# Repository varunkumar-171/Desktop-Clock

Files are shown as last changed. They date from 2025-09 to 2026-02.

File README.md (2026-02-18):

# Desktop-Clock

| PCB - Back View | PCB - Front View |
| :---: | :---: |
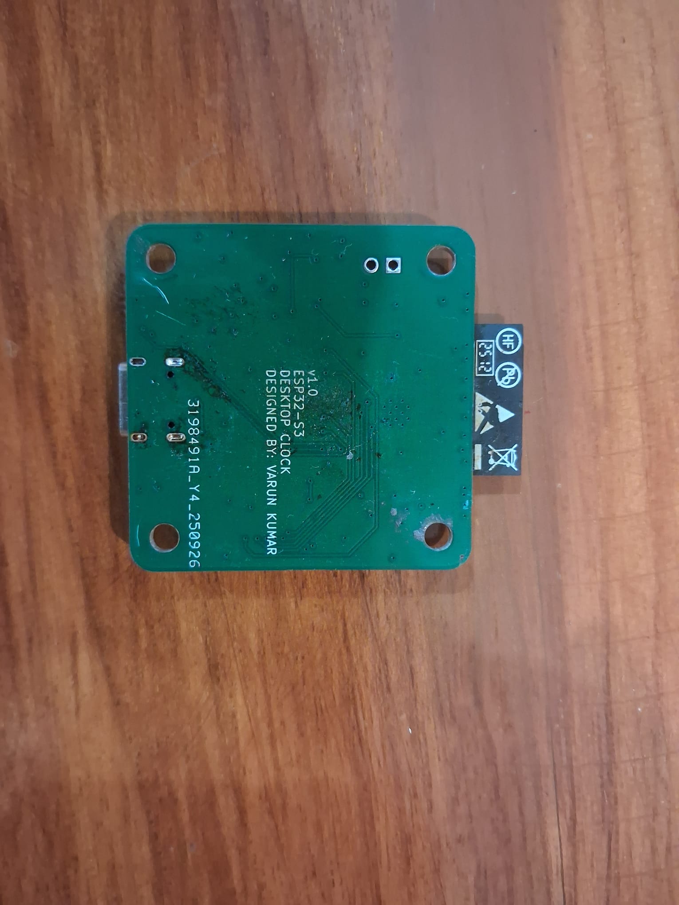
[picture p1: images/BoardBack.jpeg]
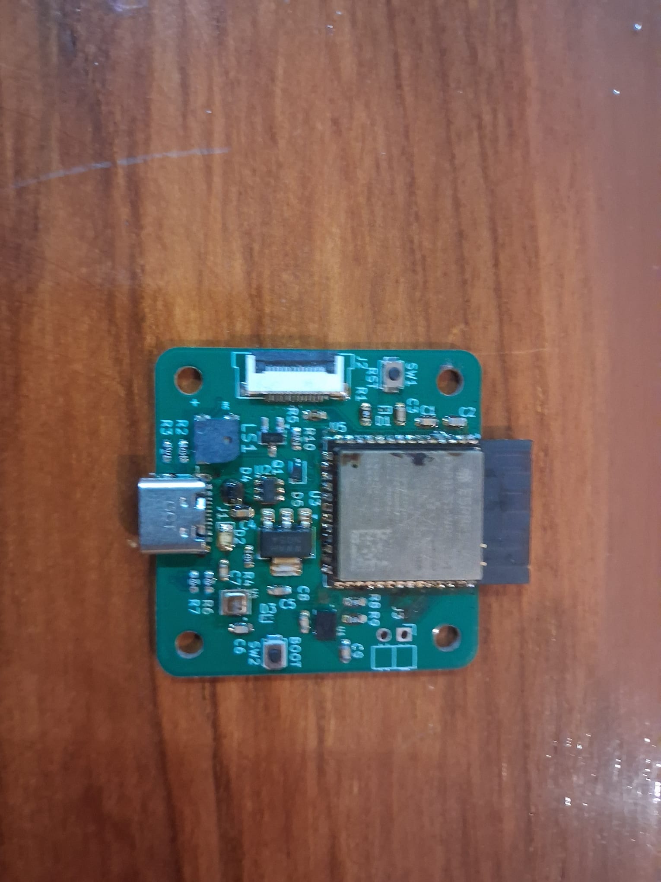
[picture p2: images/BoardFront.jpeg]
|  |  |

| Clock - Front View | Clock - Side View |
| :---: | :---: |
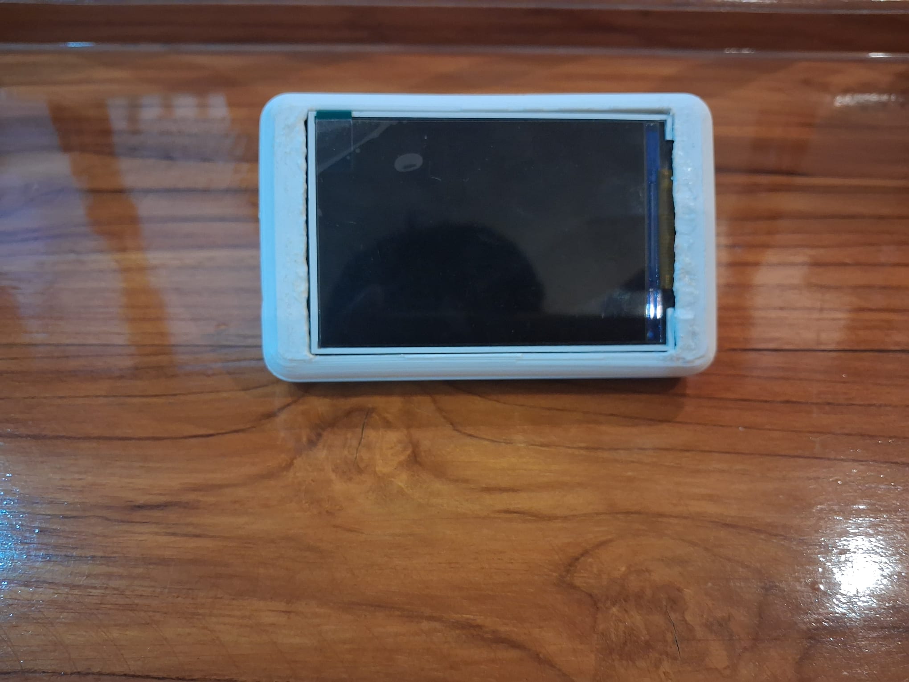
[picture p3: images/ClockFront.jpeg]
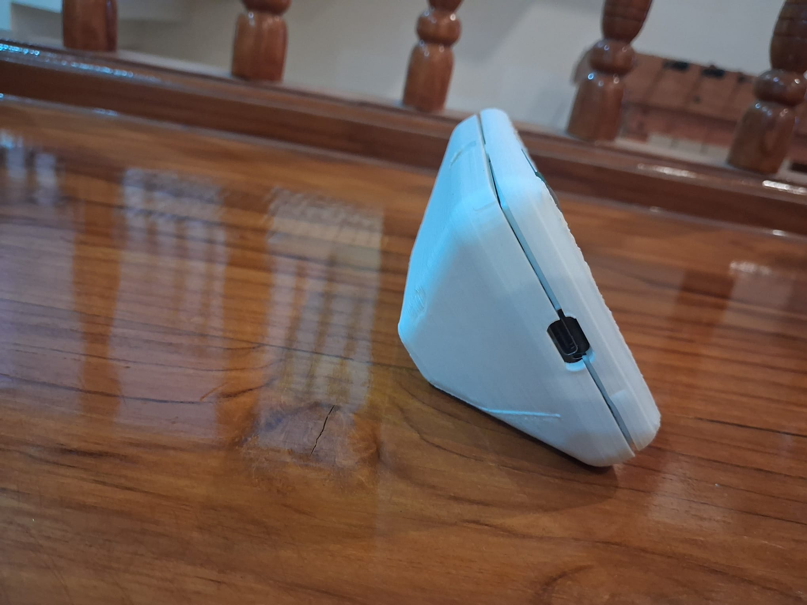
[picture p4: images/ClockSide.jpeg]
|  |  |

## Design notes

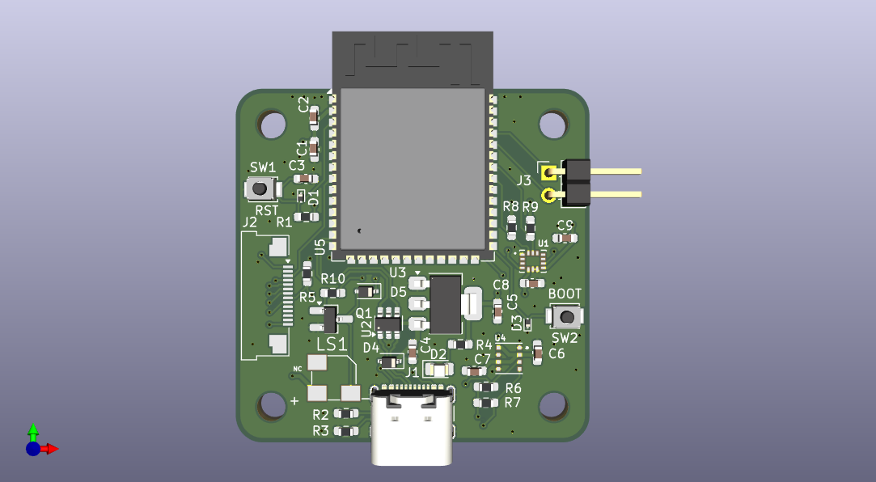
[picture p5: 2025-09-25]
hardware/DesktopClock.png

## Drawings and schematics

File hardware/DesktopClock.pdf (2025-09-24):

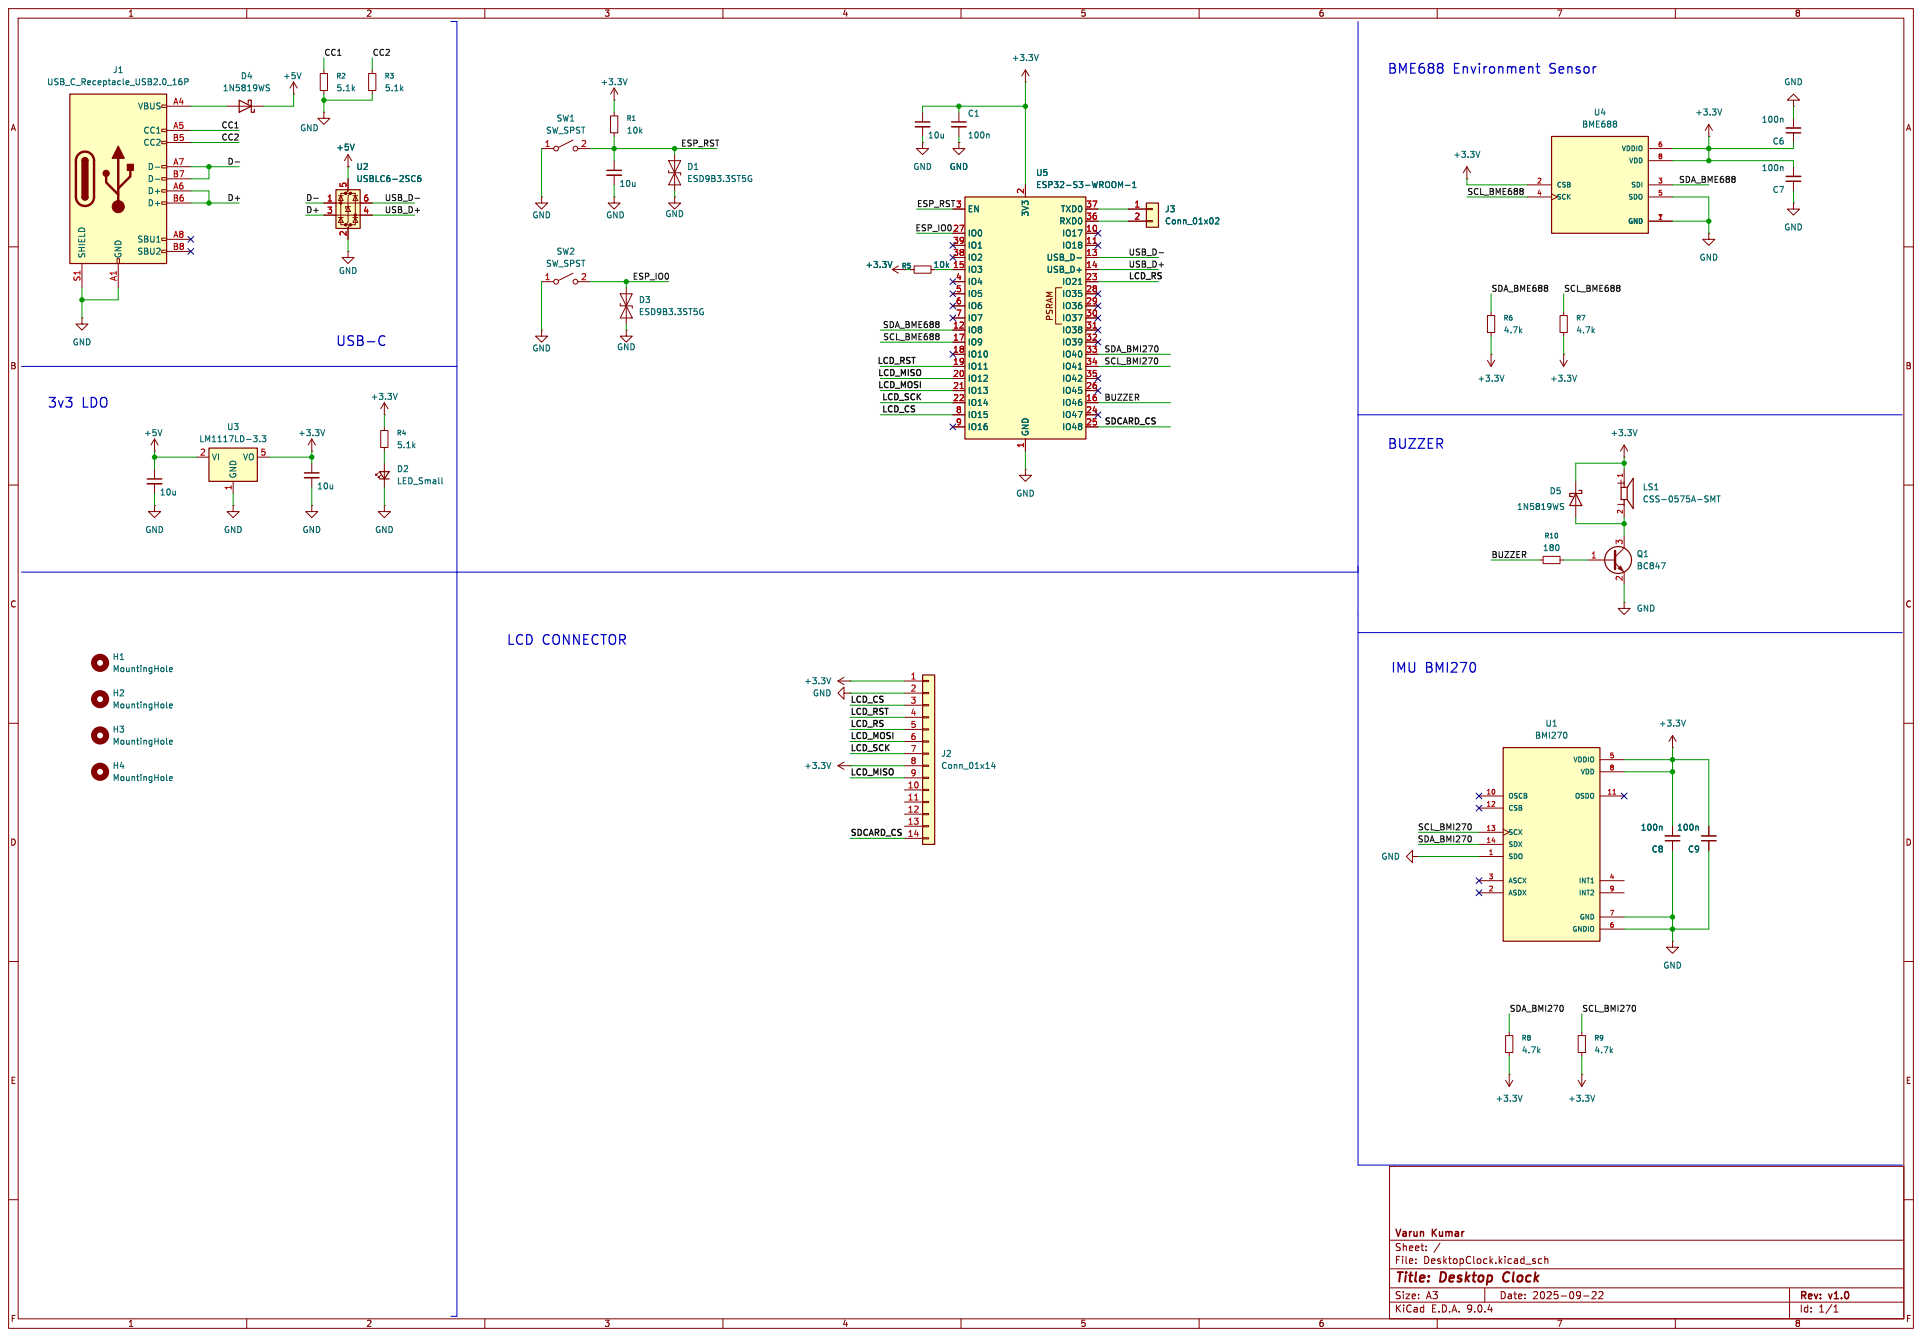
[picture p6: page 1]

Id: 1/1 Title: Desktop Clock

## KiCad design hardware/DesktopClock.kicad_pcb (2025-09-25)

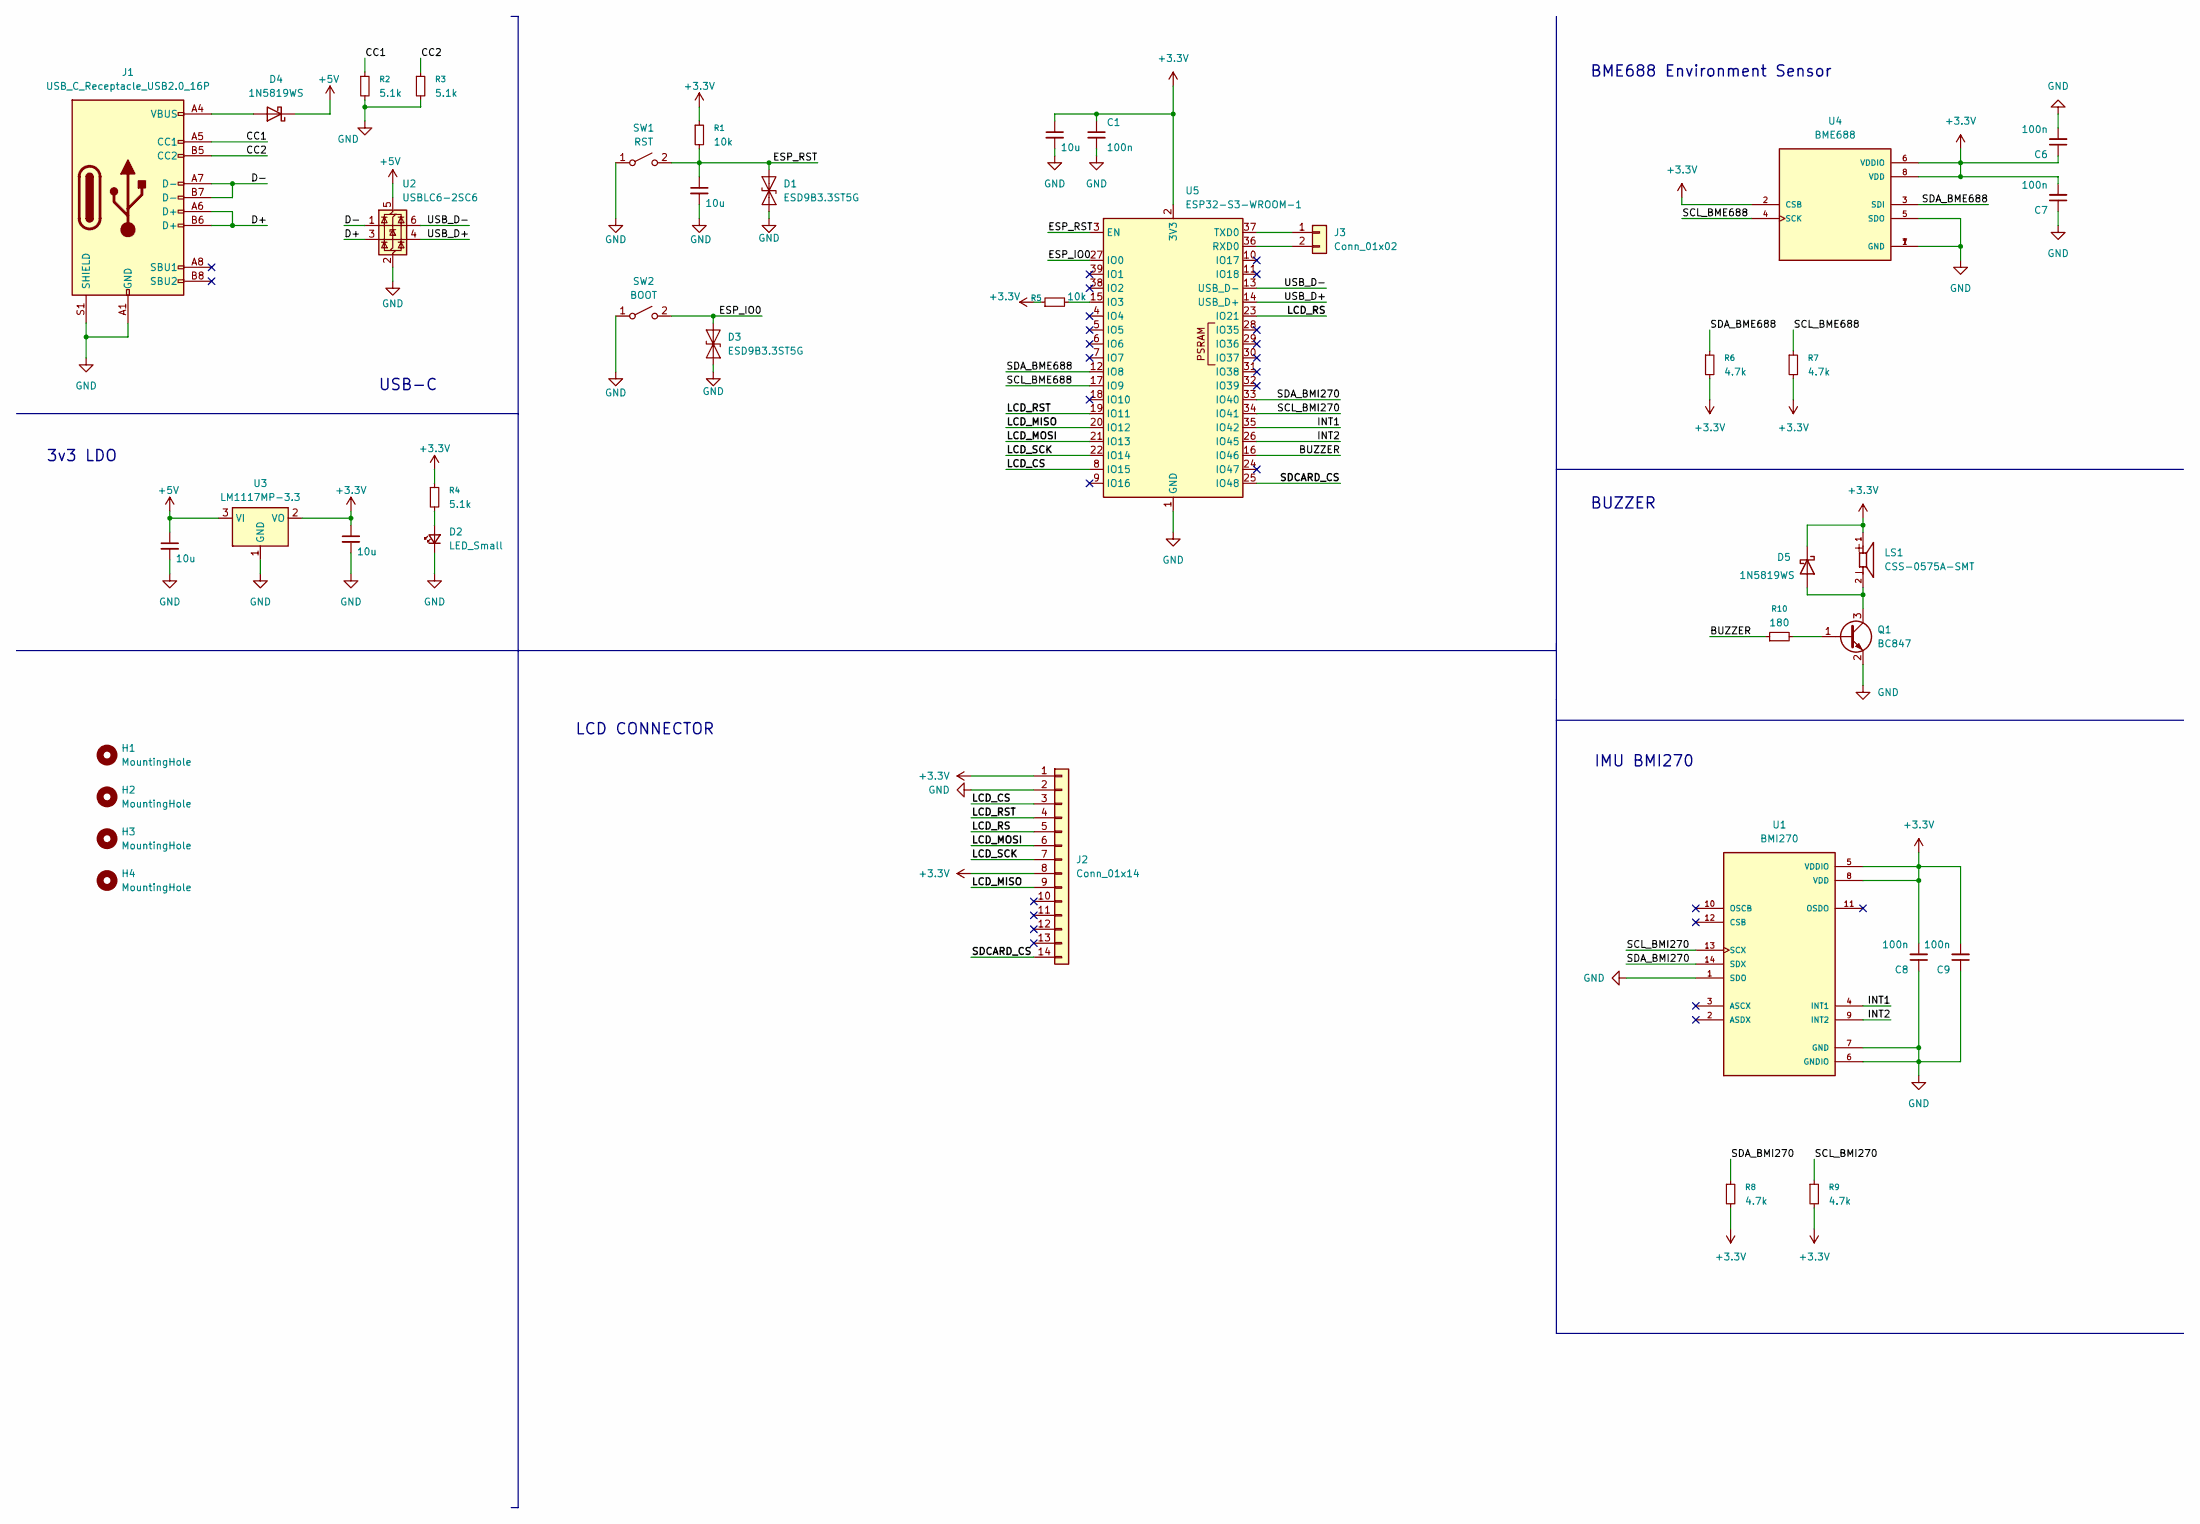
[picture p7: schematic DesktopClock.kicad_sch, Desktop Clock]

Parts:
C1, C6, C7, C8, C9: 100n; C_0603_1608Metric_Pad1.08x0.95mm_HandSolder
C2, C3, C4, C5: 10u; C_0603_1608Metric_Pad1.08x0.95mm_HandSolder
D1, D3: ESD9B3.3ST5G; D_SOD-923
D2: LED_Small; LED_0805_2012Metric_Pad1.15x1.40mm_HandSolder
D4, D5: 1N5819WS; D_SOD-323
H1, H2, H3, H4: MountingHole; MountingHole_3.2mm_M3
J1: USB_C_Receptacle_USB2.0_16P; USB_C_Receptacle_GCT_USB4105-xx-A_16P_TopMnt_Horizontal
J2: Conn_01x14; Amphenol_F32Q-1A7x1-11014_1x14-1MP_P0.5mm_Horizontal
J3: Conn_01x02; PinHeader_1x02_P2.54mm_Horizontal
LS1: CSS-0575A-SMT; CUI_CSS-0575A-SMT
Q1: BC847; SOT-23_Handsoldering
R1, R5: 10k; R_0603_1608Metric_Pad0.98x0.95mm_HandSolder
R2, R3, R4: 5.1k; R_0603_1608Metric_Pad0.98x0.95mm_HandSolder
R6, R7, R8, R9: 4.7k; R_0603_1608Metric_Pad0.98x0.95mm_HandSolder
R10: 180; R_0603_1608Metric_Pad0.98x0.95mm_HandSolder
SW1: RST; SW_SPST_B3U-1000P
SW2: BOOT; SW_SPST_B3U-1000P
U1: BMI270; XDCR_BMI270
U2: USBLC6-2SC6; SOT-23-6
U3: LM1117MP-3.3; SOT-223-3_TabPin2
U4: BME688; IC_BME688; PARTREV 1.0
U5: ESP32-S3-WROOM-1

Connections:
+3.3V: C1.1, C2.1, C5.1, C6.1, C7.2, C8.2, C9.2, D5.1 (K), J2.1, J2.8, LS1.1, R1.1, R4.1, R5.1, R6.2, R7.2, R8.2, R9.2, U1.5 (VDDIO), U1.8 (VDD), U3.2 (VO), U4.2 (CSB), U4.6 (VDDIO), U4.8 (VDD), U5.2 (3V3)
+5V: C4.1, D4.1 (K), U2.5 (VBUS), U3.3 (VI)
/BUZZER: R10.1, U5.16 (IO46)
/CC1: J1.A5 (CC1), R2.1
/CC2: J1.B5 (CC2), R3.1
/D+: J1.A6 (D+), J1.B6 (D+), U2.3 (I/O2)
/D-: J1.A7 (D-), J1.B7 (D-), U2.1 (I/O1)
/ESP_IO0: D3.2 (A2), SW2.2 (B), U5.27 (IO0)
/ESP_RST: C3.1, D1.2 (A2), R1.2, SW1.2 (B), U5.3 (EN)
/INT1: U1.4 (INT1), U5.35 (IO42)
/INT2: U1.9 (INT2), U5.26 (IO45)
/LCD_CS: J2.3, U5.8 (IO15)
/LCD_MISO: J2.9, U5.20 (IO12)
/LCD_MOSI: J2.6, U5.21 (IO13)
/LCD_RS: J2.5, U5.23 (IO21)
/LCD_RST: J2.4, U5.19 (IO11)
/LCD_SCK: J2.7, U5.22 (IO14)
/SCL_BME688: R7.1, U4.4 (SCK), U5.17 (IO9)
/SCL_BMI270: R9.1, U1.13 (SCX), U5.34 (IO41)
/SDA_BME688: R6.1, U4.3 (SDI), U5.12 (IO8)
/SDA_BMI270: R8.1, U1.14 (SDX), U5.33 (IO40)
/SDCARD_CS: J2.14, U5.25 (IO48)
/USB_D+: U2.4 (I/O2), U5.14 (USB_D+)
/USB_D-: U2.6 (I/O1), U5.13 (USB_D-)
GND: C1.2, C2.2, C3.2, C4.2, C5.2, C6.2, C7.1, C8.1, C9.1, D1.1 (A1), D2.1 (K), D3.1 (A1), J1.A1 (GND), J1.A12 (GND), J1.B1 (GND), J1.B12 (GND), J1.S1 (SHIELD), J2.2, Q1.2 (E), R2.2, R3.2, SW1.1 (A), SW2.1 (A), U1.1 (SDO), U1.6 (GNDIO), U1.7 (GND), U2.2 (GND), U3.1 (GND), U4.1 (GND), U4.5 (SDO), U4.7 (GND), U5.1 (GND), U5.40 (GND), U5.41 (GND)
unnamed: D2.2 (A), R4.2
unnamed: D4.2 (A), J1.A4 (VBUS), J1.A9 (VBUS), J1.B4 (VBUS), J1.B9 (VBUS)
unnamed: D5.2 (A), LS1.2, Q1.3 (C)
unnamed: J3.1, U5.37 (TXD0)
unnamed: J3.2, U5.36 (RXD0)
unnamed: Q1.1 (B), R10.2
unnamed: R5.2, U5.15 (IO3)

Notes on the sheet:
USB-C
IMU BMI270
BME688 Environment Sensor
LCD CONNECTOR
3v3 LDO
BUZZER

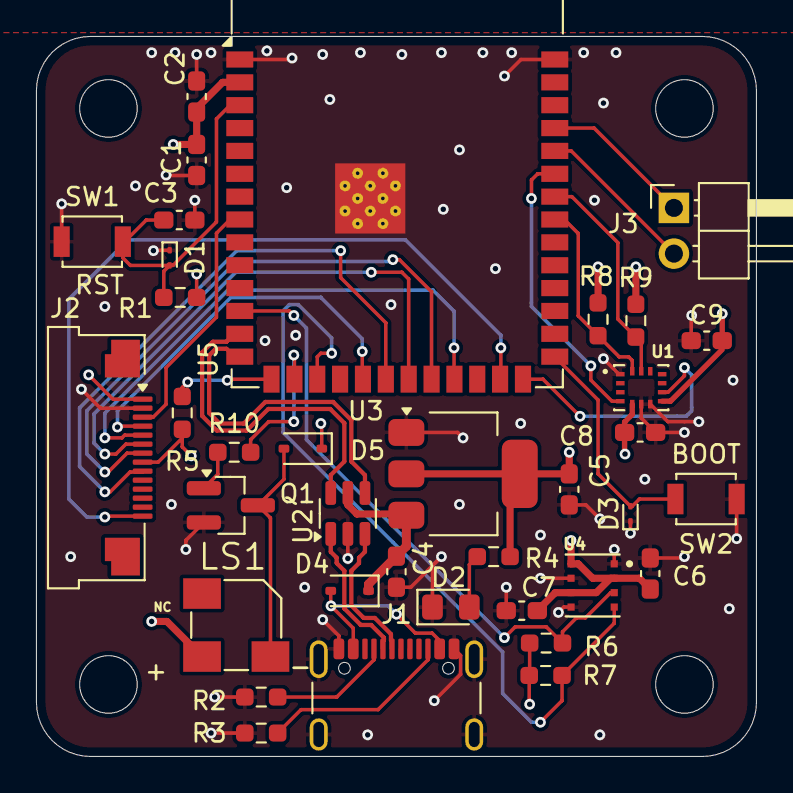
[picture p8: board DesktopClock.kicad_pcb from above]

Board: 4 copper layers, 40.0 x 40.0 mm, 40 parts (0 on the bottom side), 32 nets.

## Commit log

2025-09-23 schem rev1.0
    [DesktopClock.kicad_pcb, DesktopClock.kicad_sch]
2025-09-23 schem ver1.0
    [DesktopClock.kicad_sch]
2025-09-24 rev 3.0
    [DesktopClock.kicad_sch]
2025-09-25 Layout complete
    [DesktopClock.kicad_pcb, DesktopClock.kicad_sch]
